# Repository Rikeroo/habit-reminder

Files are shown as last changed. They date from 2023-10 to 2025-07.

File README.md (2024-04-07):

# Habit Reminder
Low energy physical habit reminder, using RGB LEDs, a small task screen and tactile switches to build useful habits and get tasks done

## DevBoard Prototype:
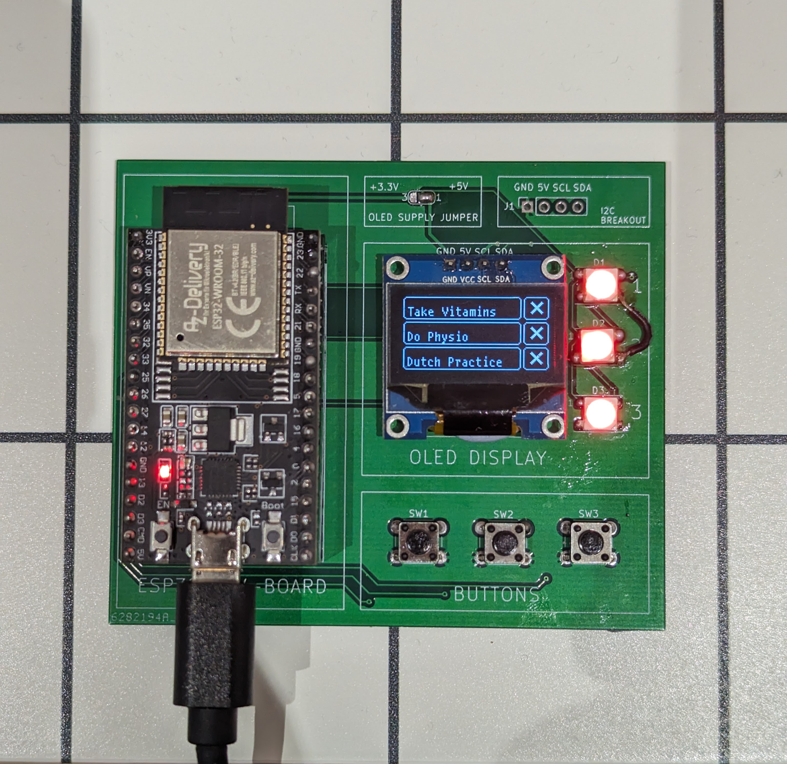
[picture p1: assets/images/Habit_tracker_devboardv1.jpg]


## ESP-32 WROOM Board Render:
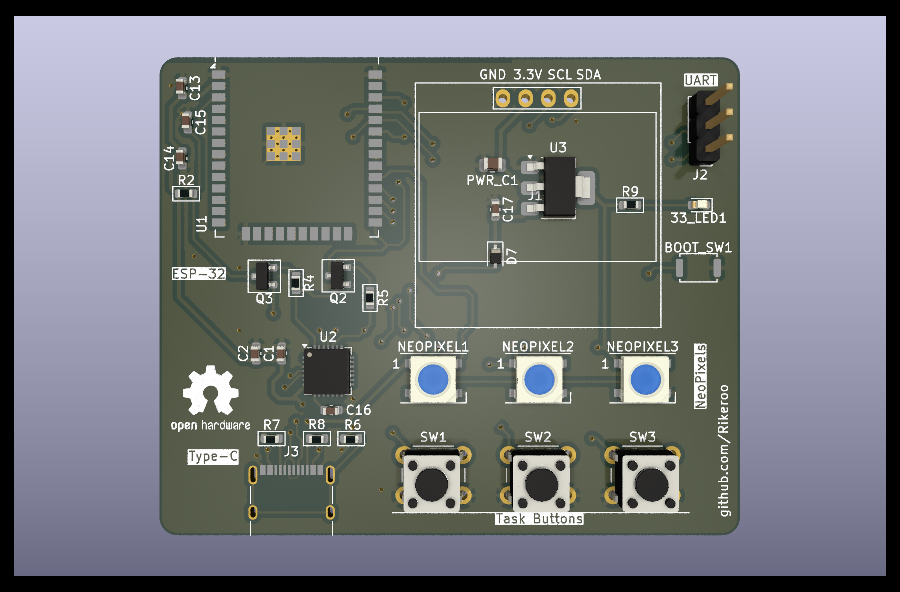
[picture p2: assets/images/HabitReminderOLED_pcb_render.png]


## Features
- OLED screen to display tasks
- NeoPixel WS281b LED modules to show completion at a glance
- Tactile buttons to complete tasks
## Planned Features
- Integration with ToDoist API, with 2-way sync
- FreeRTOS Implementation for easy scheduling
- Speaker for audible task complete sound
- Enclosure/Stand for flexible display options
- Points/Streaks counter
- LED Integrated buttons? (RBG mech switches)

## Learnt from DevBoard V1 Manufacture and build
- WS2812b fine with 5V supply and 3.3V logic
- Status LED would be usefull for de-bugging
- 4 Pin Female socket for screen would make build easier
- Feet required, or Command strip mounting, or enclosure
- Moving NeoPixels away from screen would make for easier soldering
- Add mounting holes to main pcb for enclosure

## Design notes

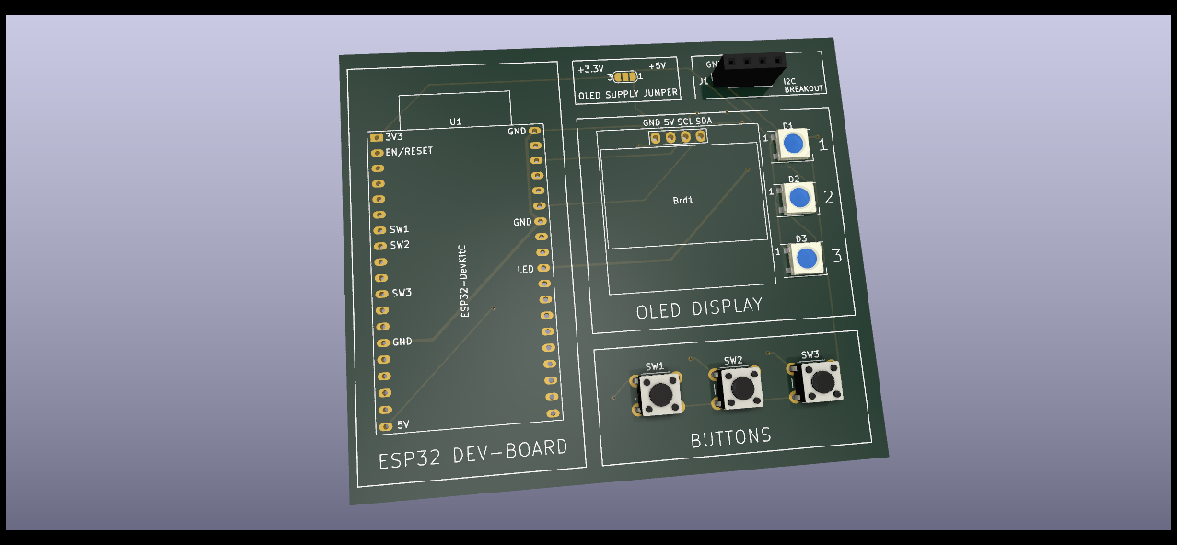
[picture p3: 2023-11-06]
pcb/dev-board-habit-reminder/Dev_habit_reminder/Dev_habit_reminder.png

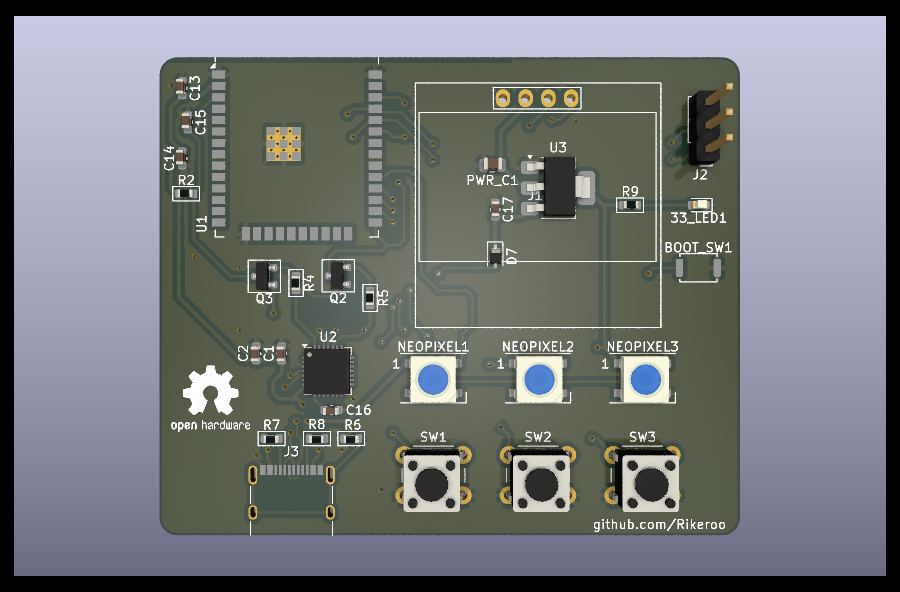
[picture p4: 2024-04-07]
pcb/HabitReminderXAIO/HabitReminderOLED_pcb_render.png

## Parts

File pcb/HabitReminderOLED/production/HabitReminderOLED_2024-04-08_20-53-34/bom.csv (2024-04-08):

Designator | Footprint | Quantity | Value | LCSC Part #
33_LED1 | 0603 | 1 | 3.3 LED
BOOT_SW1 | SW_Push_SPST_NO_Alps_SKRK | 1 | Boot
C1 | 0603 | 1 | 4.7uF
C13, C16, C17 | 0603 | 3 | 10uF
C14, C15, C2 | 0603 | 3 | 0.1uF
D7 | D_SOD-323 | 1 | 1N5819WS
J1 | 128x64OLED_No_Holes | 1 | I2C Sockets
J2 | PinHeader_1x03_P2.54mm_Vertical | 1 | UART Pins
J3 | USB_C_Receptacle_XKB_U262-16XN-4BVC11 | 1 | USB_C_Receptacle_USB2.0_16P
NEOPIXEL1, NEOPIXEL2, NEOPIXEL3 | LED_WS2812B_PLCC4_5.0x5.0mm_P3.2mm | 3 | WS2812B
PWR_C1 | 0805 | 1 | 10uF
Q2, Q3 | SOT-23 | 2 | S8050
R2 | 0603 | 1 | 10k
R4, R5 | 0603 | 2 | 12K
R6 | 0603 | 1 | 1M
R7, R8 | 0603 | 2 | 5.11K
R9 | 0603 | 1 | 2.2K
SW1 | SW_PUSH_6mm | 1 | PUSH_1
SW2 | SW_PUSH_6mm | 1 | PUSH_2
SW3 | SW_PUSH_6mm | 1 | PUSH_3
U1 | ESP32-WROOM-32D | 1 | ESP32-WROOM-32D
U2 | QFN-28-1EP_5x5mm_P0.5mm_EP3.35x3.35mm | 1 | CP2102N-Axx-xQFN28
U3 | SOT-223-3_TabPin2 | 1 | AMS1117-3.3

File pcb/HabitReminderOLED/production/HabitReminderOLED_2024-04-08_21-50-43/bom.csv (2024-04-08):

Designator | Footprint | Quantity | Value | LCSC Part #
33_LED1 | 0603 | 1 | 3.3 LED | C965799
BOOT_SW1 | SW_Push_SPST_NO_Alps_SKRK | 1 | Boot | C455280
C1 | 0603 | 1 | 4.7uF
C13, C16, C17 | 0603 | 3 | 10uF
C14, C15, C2 | 0603 | 3 | 0.1uF
D7 | D_SOD-323 | 1 | 1N5819WS
J1 | 128x64OLED_No_Holes | 1 | I2C Sockets | C2718488
J2 | PinHeader_1x03_P2.54mm_Vertical | 1 | UART Pins | C49257
J3 | USB_C_Receptacle_XKB_U262-16XN-4BVC11 | 1 | USB_C_Receptacle_USB2.0_16P | C319148
NEOPIXEL1, NEOPIXEL2, NEOPIXEL3 | LED_WS2812B_PLCC4_5.0x5.0mm_P3.2mm | 3 | WS2812B | C2843785
PWR_C1 | 0805 | 1 | 10uF
Q2, Q3 | SOT-23 | 2 | S8050 | C916390
R2 | 0603 | 1 | 10k
R4, R5 | 0603 | 2 | 12K
R6 | 0603 | 1 | 1M
R7, R8 | 0603 | 2 | 5.11K
R9 | 0603 | 1 | 2.2K
SW1 | SW_Push_1P1T_NO_6x6mm_H9.5mm | 1 | PUSH_1 | C455110
SW2 | SW_Push_1P1T_NO_6x6mm_H9.5mm | 1 | PUSH_2 | C455110
SW3 | SW_Push_1P1T_NO_6x6mm_H9.5mm | 1 | PUSH_3 | C455110
U1 | ESP32-WROOM-32D | 1 | ESP32-WROOM-32D
U2 | QFN-28-1EP_5x5mm_P0.5mm_EP3.35x3.35mm | 1 | CP2102N-Axx-xQFN28 | C964632
U3 | SOT-223-3_TabPin2 | 1 | AMS1117-3.3 | C347222

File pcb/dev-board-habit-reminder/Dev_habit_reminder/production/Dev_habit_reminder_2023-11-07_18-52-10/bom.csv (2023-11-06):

Designator | Footprint | Quantity | Value | LCSC Part #
Brd1 | 128x64OLED_No_Holes | 1 | SSD1306
D1, D2, D3 | LED_WS2812B_PLCC4_5.0x5.0mm_P3.2mm | 3 | WS2812B
J1 | PinSocket_1x04_P2.54mm_Vertical | 1 | I2C BREAKOUT
JP1 | SolderJumper-3_P1.3mm_Bridged12_RoundedPad1.0x1.5mm_NumberLabels | 1 | SolderJumper_5V_3V3
SW1, SW2, SW3 | SW_PUSH_6mm | 3 | SW_Push
U1 | ESP32-DevKitC_Shield2 | 1 | ESP32-DevKitC

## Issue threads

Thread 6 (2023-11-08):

Add mmWave presence sensor to dev-board

Rikeroo, 2023-11-08:

Rikeroo, 2023-11-08:
Not worth it - oled doesn't consume much power and presence sensor library not trivial to communicate with

Closed 2023-11-08.

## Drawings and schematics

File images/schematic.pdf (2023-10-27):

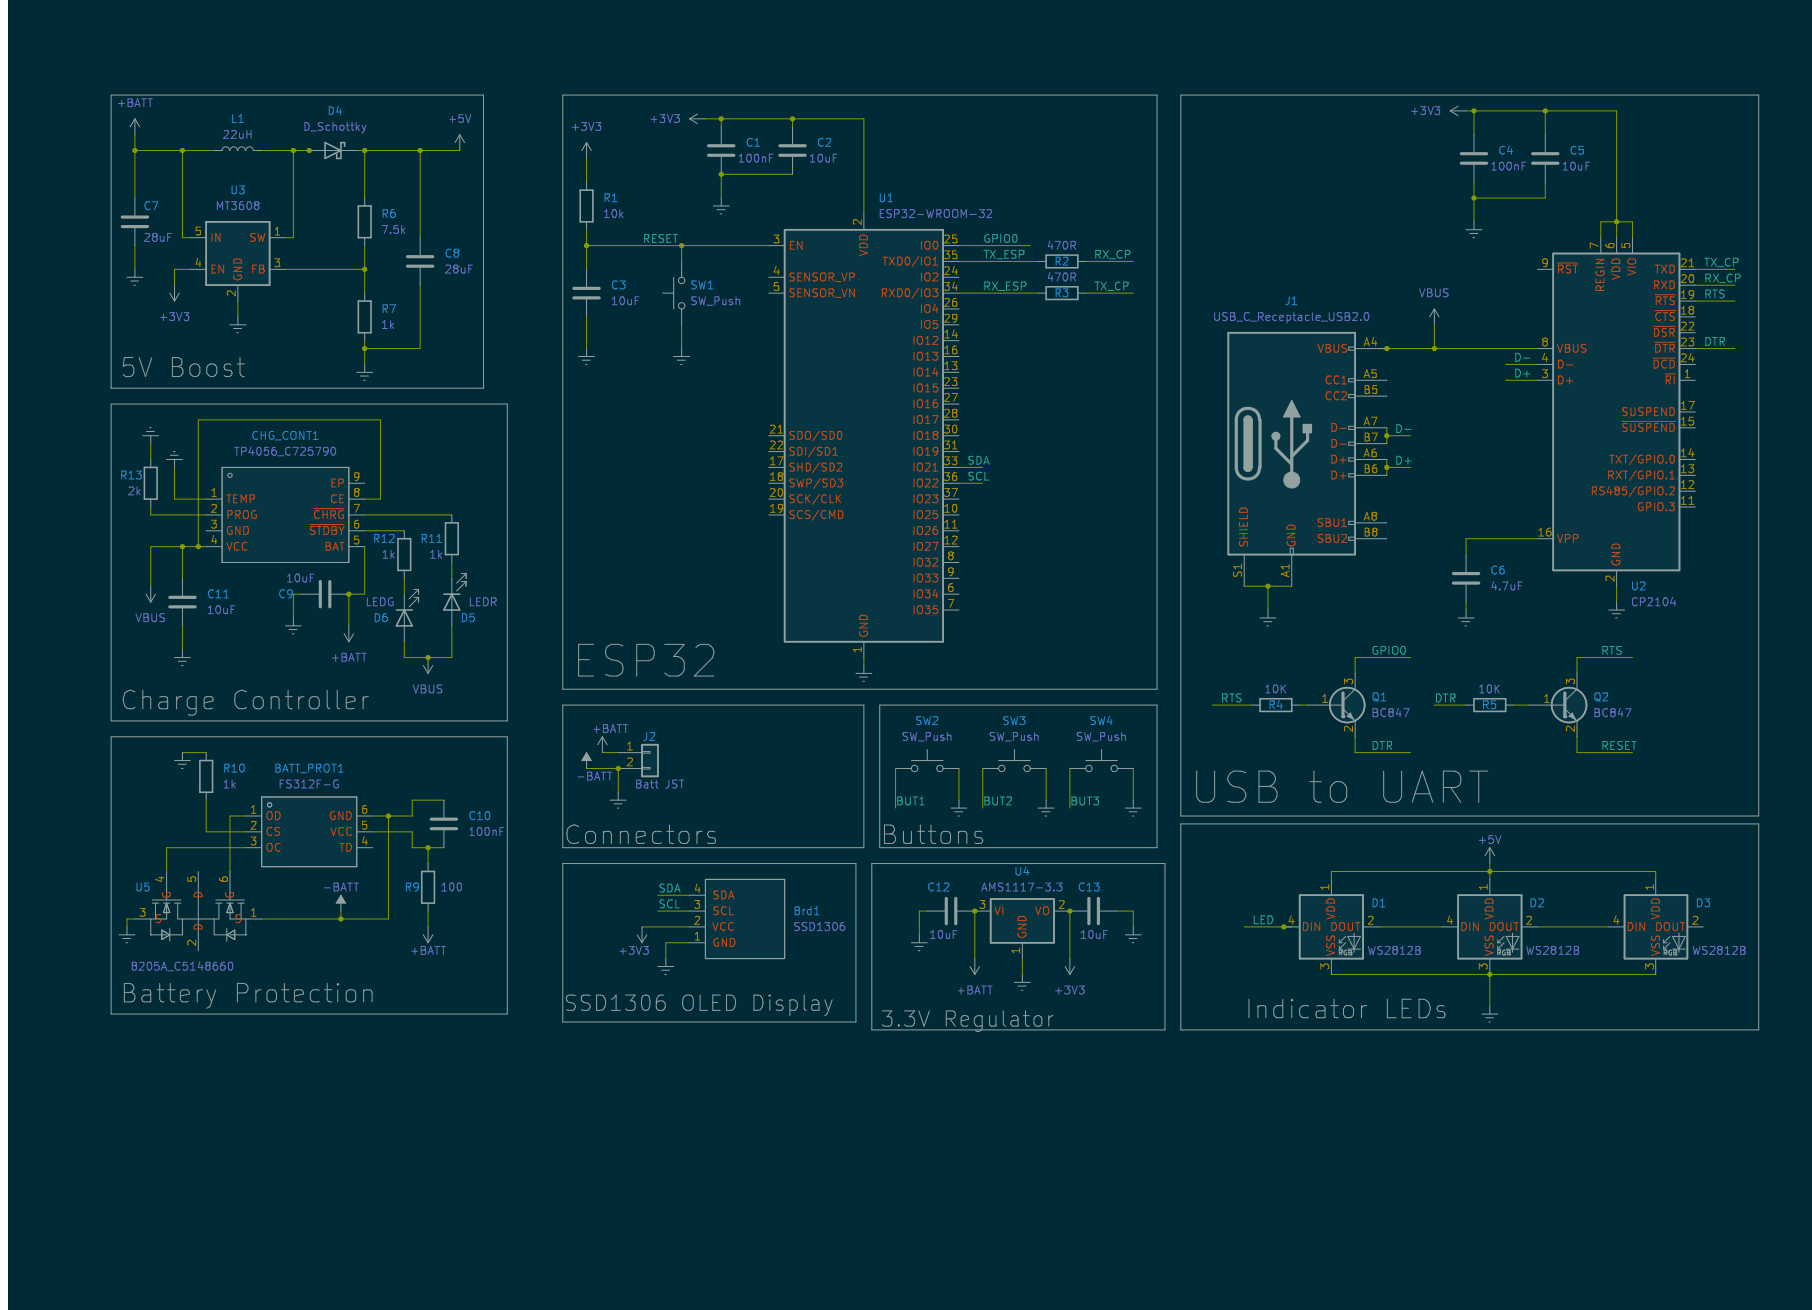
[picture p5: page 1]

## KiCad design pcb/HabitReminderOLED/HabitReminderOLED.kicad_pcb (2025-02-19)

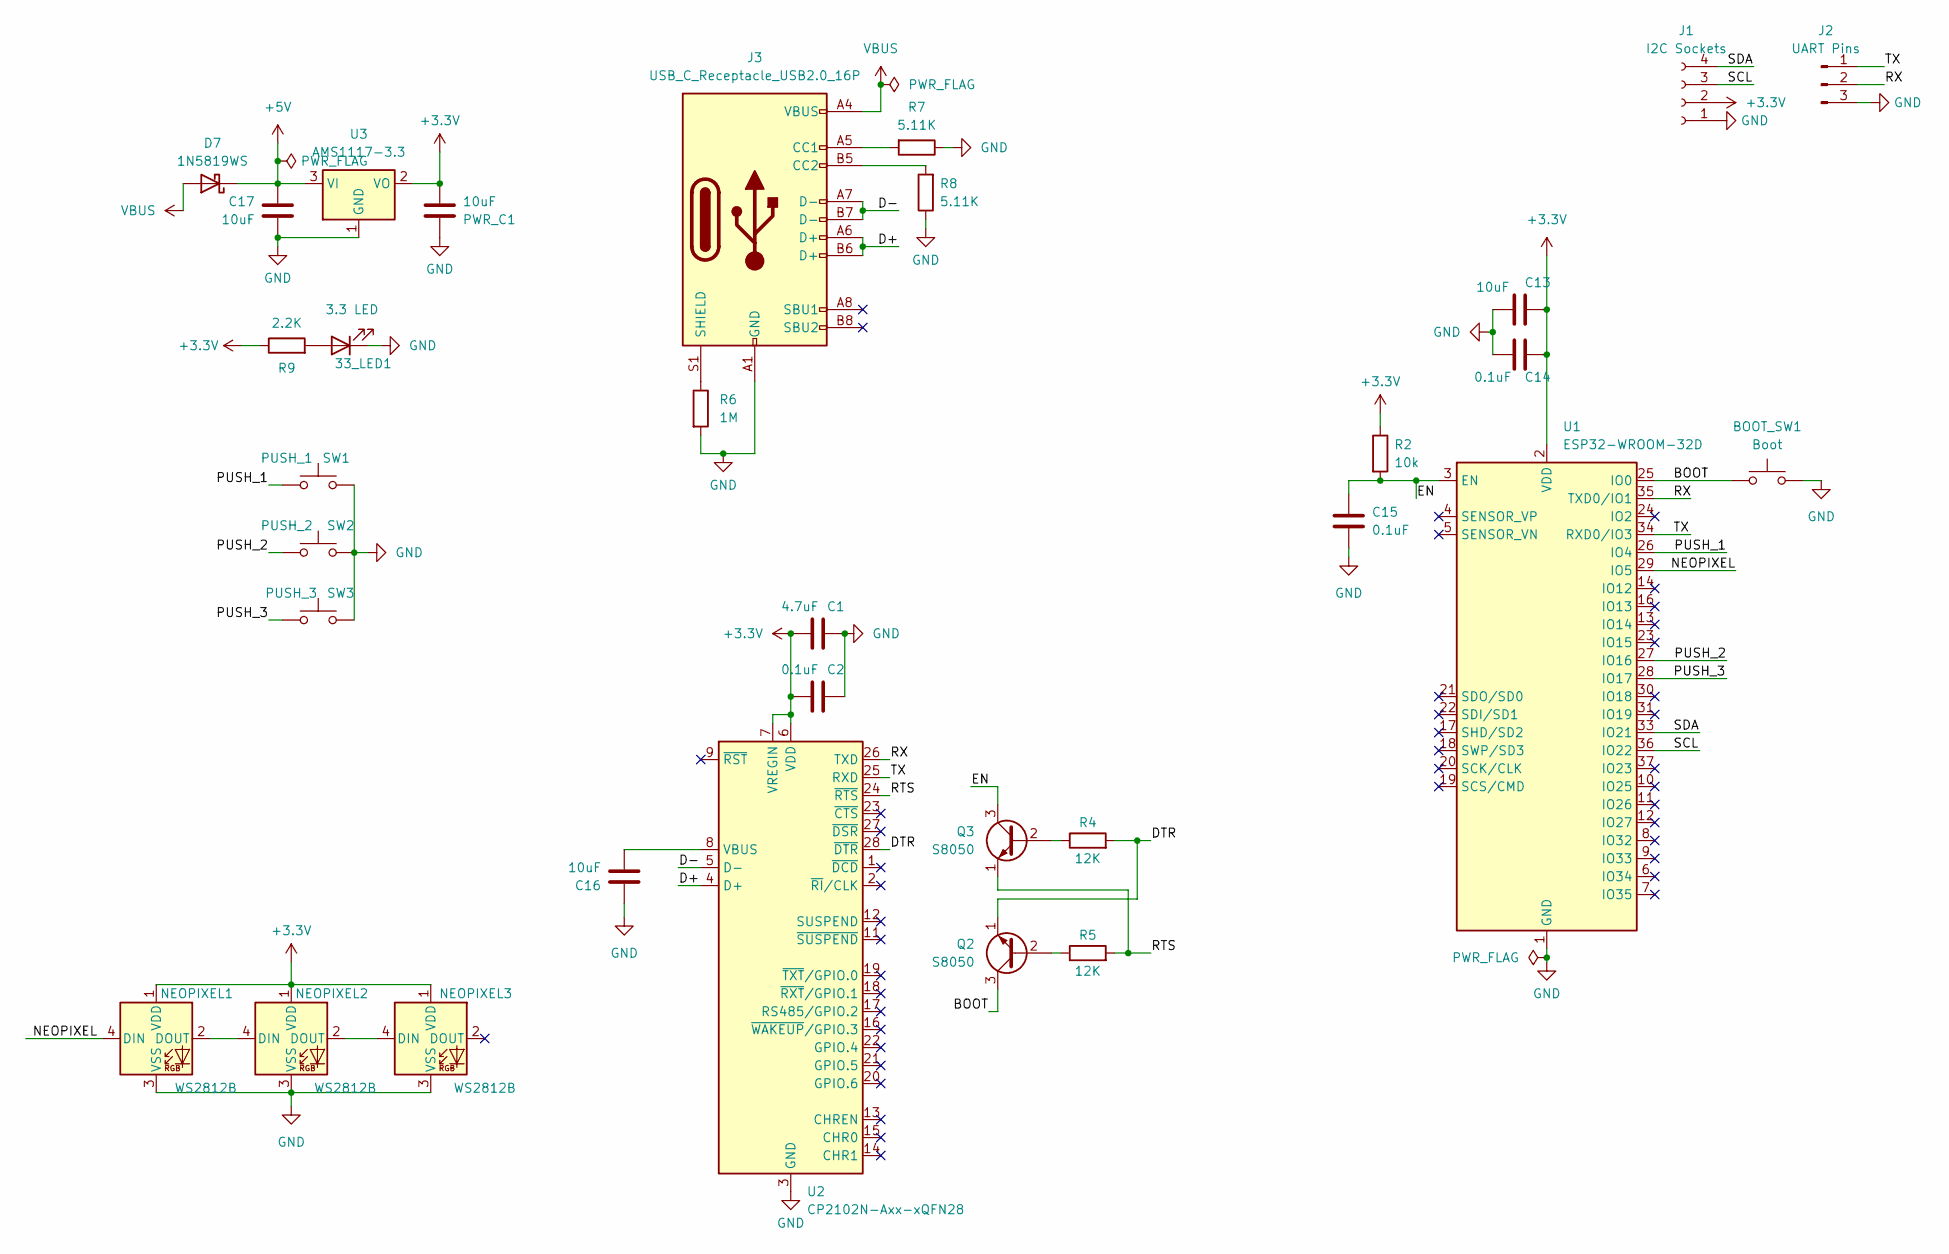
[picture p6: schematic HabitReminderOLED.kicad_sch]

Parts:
33_LED1: 3.3 LED; LED_0603_1608Metric; LCSC C965799
BOOT_SW1: Boot; SW_Push_SPST_NO_Alps_SKRK; LCSC C455280
C1: 4.7uF; C_0603_1608Metric; LCSC C1705
C2, C14, C15: 0.1uF; C_0603_1608Metric; LCSC C30926
C13, C16, C17: 10uF; C_0603_1608Metric; LCSC C77044
D7: 1N5819WS; D_SOD-323; LCSC C2828425
J1: I2C Sockets; 128x64OLED_No_Holes; LCSC C2718488
J2: UART Pins; PinHeader_1x03_P2.54mm_Vertical; LCSC C49257
J3: USB_C_Receptacle_USB2.0_16P; USB_C_Receptacle_XKB_U262-16XN-4BVC11; LCSC C319148
NEOPIXEL1, NEOPIXEL2, NEOPIXEL3: WS2812B; LED_WS2812B_PLCC4_5.0x5.0mm_P3.2mm; LCSC C2843785
PWR_C1: 10uF; C_0805_2012Metric; LCSC C15850
Q2, Q3: S8050; SOT-23; LCSC C916390
R2: 10k; R_0603_1608Metric; LCSC C25804
R4, R5: 12K; R_0603_1608Metric; LCSC C114659
R6: 1M; R_0603_1608Metric; LCSC C26098
R7, R8: 5.11K; R_0603_1608Metric; LCSC C2933233
R9: 2.2K; R_0603_1608Metric; LCSC C4190
SW1: PUSH_1; SW_Push_1P1T_NO_6x6mm_H9.5mm; LCSC C455110
SW2: PUSH_2; SW_Push_1P1T_NO_6x6mm_H9.5mm; LCSC C455110
SW3: PUSH_3; SW_Push_1P1T_NO_6x6mm_H9.5mm; LCSC C455110
U1: ESP32-WROOM-32D; LCSC C473012
U2: CP2102N-Axx-xQFN28; QFN-28-1EP_5x5mm_P0.5mm_EP3.35x3.35mm; LCSC C964632
U3: AMS1117-3.3; SOT-223-3_TabPin2; LCSC C347222

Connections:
+3.3V: C1.1, C2.1, C13.2, C14.2, J1.2, NEOPIXEL1.1 (VDD), NEOPIXEL2.1 (VDD), NEOPIXEL3.1 (VDD), PWR_C1.1, R2.1, R9.1, U1.2 (VDD), U2.6 (VDD), U2.7 (VREGIN), U3.2 (VO)
+5V: C17.2, D7.1 (K), U3.3 (VI)
/BOOT: BOOT_SW1.1, Q2.3 (C), U1.25 (IO0)
/D+: J3.A6 (D+), J3.B6 (D+), U2.4 (D+)
/D-: J3.A7 (D-), J3.B7 (D-), U2.5 (D-)
/DTR: Q2.1 (E), R4.2, U2.28 (~DTR)
/EN: C15.2, Q3.3 (C), R2.2, U1.3 (EN)
/NEOPIXEL: NEOPIXEL1.4 (DIN), U1.29 (IO5)
/PUSH_1: SW1.1, U1.26 (IO4)
/PUSH_2: SW2.1, U1.27 (IO16)
/PUSH_3: SW3.1, U1.28 (IO17)
/RTS: Q3.1 (E), R5.2, U2.24 (~RTS)
/RX: J2.2, U1.35 (TXD0/IO1), U2.26 (TXD)
/SCL: J1.3, U1.36 (IO22)
/SDA: J1.4, U1.33 (IO21)
/TX: J2.1, U1.34 (RXD0/IO3), U2.25 (RXD)
GND: 33_LED1.1 (K), BOOT_SW1.2, C1.2, C2.2, C13.1, C14.1, C15.1, C16.1, C17.1, J1.1, J2.3, J3.A1 (GND), J3.A12 (GND), J3.B1 (GND), J3.B12 (GND), NEOPIXEL1.3 (VSS), NEOPIXEL2.3 (VSS), NEOPIXEL3.3 (VSS), PWR_C1.2, R6.2, R7.1, R8.1, SW1.2, SW2.2, SW3.2, U1.1 (GND), U1.15 (GND), U1.38 (GND), U1.39 (GND), U2.3 (GND), U2.29 (GND), U3.1 (GND)
unnamed: 33_LED1.2 (A), R9.2
unnamed: J3.A5 (CC1), R7.2
unnamed: J3.B5 (CC2), R8.2
unnamed: J3.S1 (SHIELD), R6.1
unnamed: NEOPIXEL1.2 (DOUT), NEOPIXEL2.4 (DIN)
unnamed: NEOPIXEL2.2 (DOUT), NEOPIXEL3.4 (DIN)
unnamed: Q2.2 (B), R5.1
unnamed: Q3.2 (B), R4.1
unnamed: C16.2, U2.8 (VBUS)
VBUS: D7.2 (A), J3.A4 (VBUS), J3.A9 (VBUS), J3.B4 (VBUS), J3.B9 (VBUS)

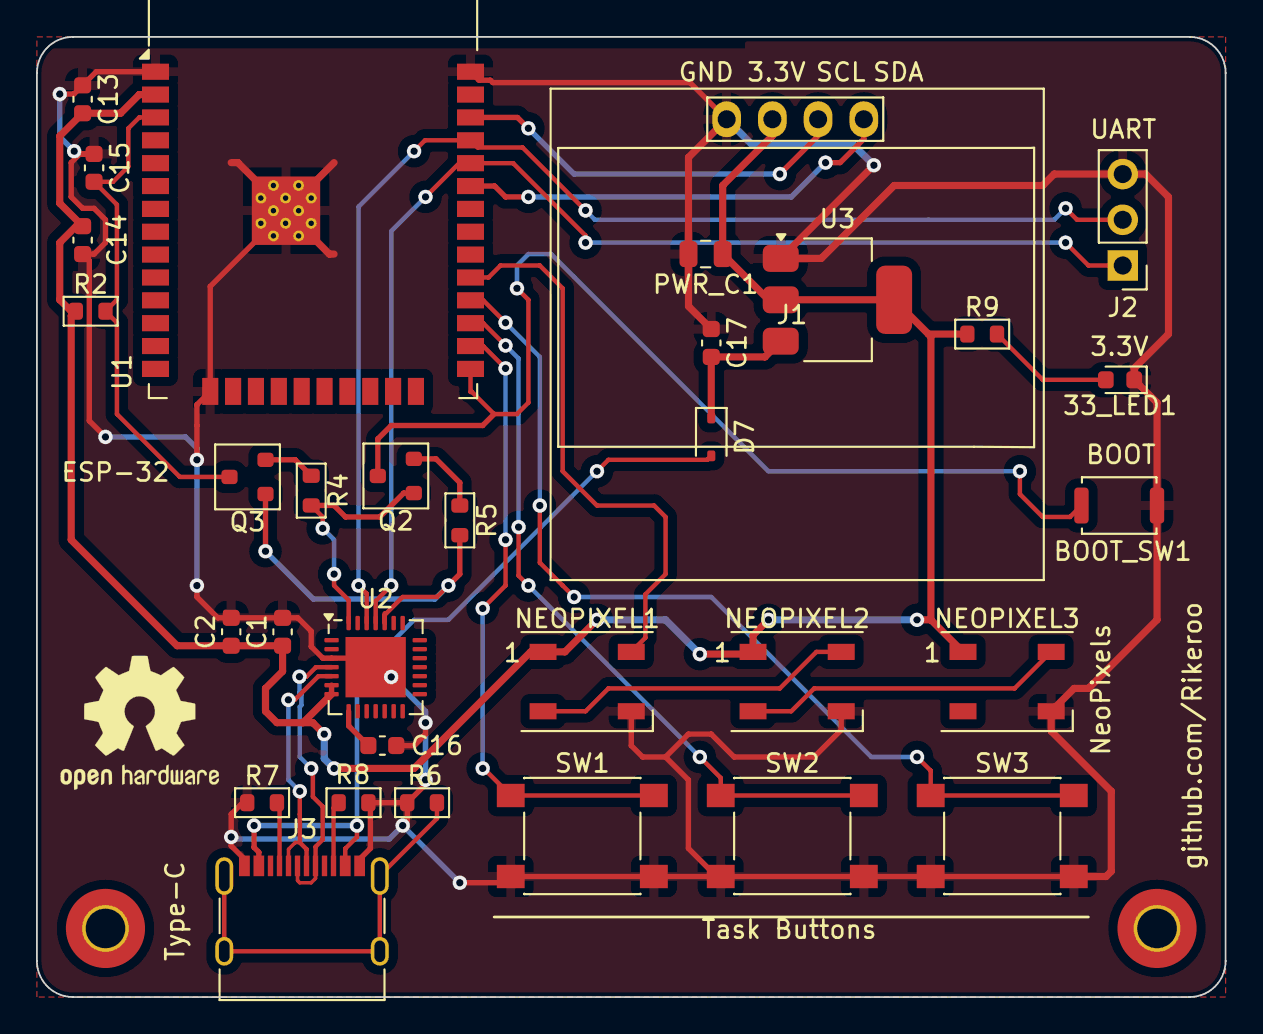
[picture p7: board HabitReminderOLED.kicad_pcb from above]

Board: 2 copper layers, 66.0 x 53.3 mm, 32 parts (0 on the bottom side), 27 nets.

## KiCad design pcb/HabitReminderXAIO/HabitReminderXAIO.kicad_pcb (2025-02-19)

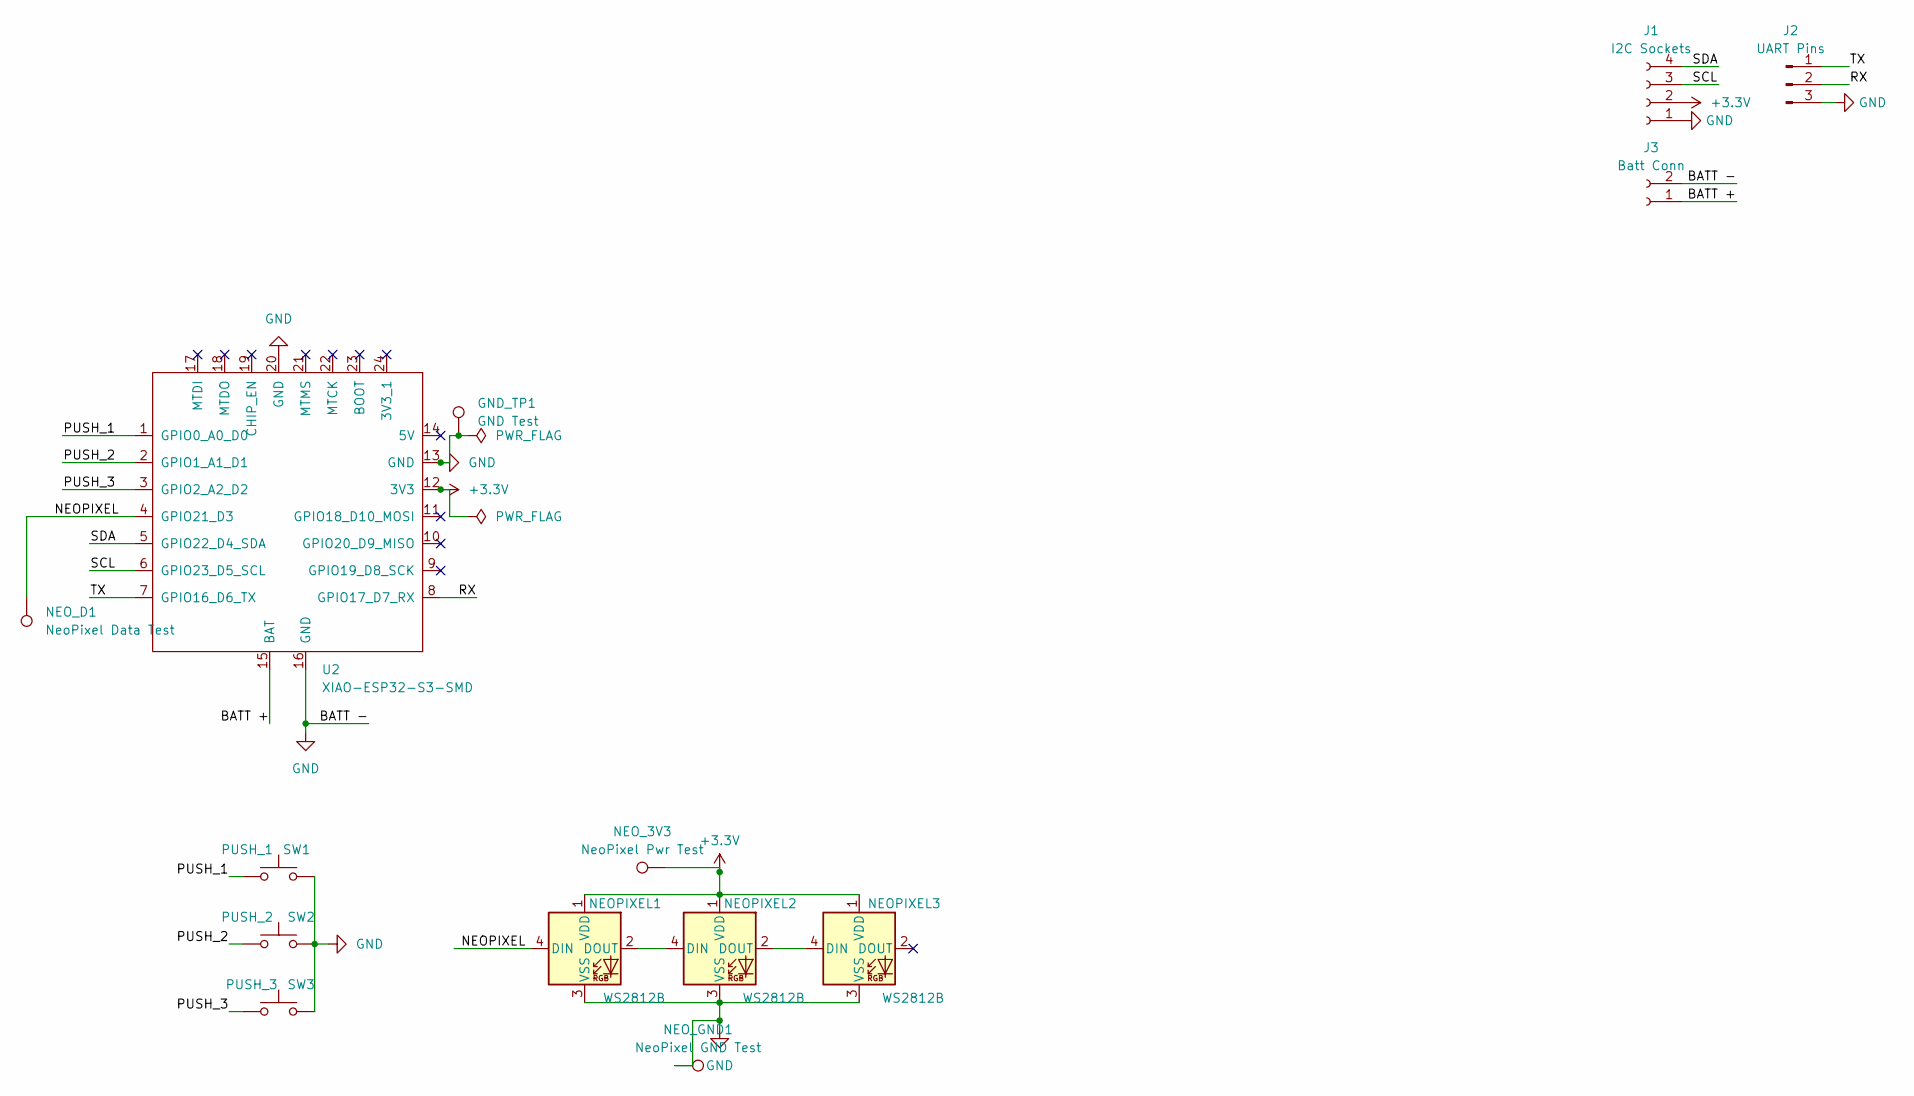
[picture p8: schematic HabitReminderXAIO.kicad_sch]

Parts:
GND_TP1: GND Test; TestPoint_Pad_D1.5mm
J1: I2C Sockets; 128x64OLED; LCSC C2718488
J2: UART Pins; PinHeader_1x03_P2.54mm_Vertical; LCSC C49257
J3: Batt Conn; JST_PH_S2B-PH-K_1x02_P2.00mm_Horizontal
NEOPIXEL1, NEOPIXEL2, NEOPIXEL3: WS2812B; LED_WS2812B_PLCC4_5.0x5.0mm_P3.2mm; LCSC C2843785
NEO_3V3: NeoPixel Pwr Test; TestPoint_Pad_D1.5mm
NEO_D1: NeoPixel Data Test; TestPoint_Pad_D1.5mm
NEO_GND1: NeoPixel GND Test; TestPoint_Pad_D1.5mm
SW1: PUSH_1; SW_Push_1P1T_NO_6x6mm_H9.5mm; LCSC C455110
SW2: PUSH_2; SW_Push_1P1T_NO_6x6mm_H9.5mm; LCSC C455110
SW3: PUSH_3; SW_Push_1P1T_NO_6x6mm_H9.5mm; LCSC C455110
U2: XIAO-ESP32-S3-SMD; XIAO-ESP32C6-SMD

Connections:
+3.3V: J1.2, NEOPIXEL1.1 (VDD), NEOPIXEL2.1 (VDD), NEOPIXEL3.1 (VDD), NEO_3V3.1, U2.12 (3V3)
/BATT +: J3.1, U2.15 (BAT)
/NEOPIXEL: NEOPIXEL1.4 (DIN), NEO_D1.1, U2.4 (GPIO21_D3)
/PUSH_1: SW1.1, U2.1 (GPIO0_A0_D0)
/PUSH_2: SW2.1, U2.2 (GPIO1_A1_D1)
/PUSH_3: SW3.1, U2.3 (GPIO2_A2_D2)
/RX: J2.2, U2.8 (GPIO17_D7_RX)
/SCL: J1.3, U2.6 (GPIO23_D5_SCL)
/SDA: J1.4, U2.5 (GPIO22_D4_SDA)
/TX: J2.1, U2.7 (GPIO16_D6_TX)
GND: GND_TP1.1, J1.1, J2.3, J3.2, NEOPIXEL1.3 (VSS), NEOPIXEL2.3 (VSS), NEOPIXEL3.3 (VSS), NEO_GND1.1, SW1.2, SW2.2, SW3.2, U2.13 (GND), U2.16 (GND), U2.20 (GND)
unnamed: NEOPIXEL1.2 (DOUT), NEOPIXEL2.4 (DIN)
unnamed: NEOPIXEL2.2 (DOUT), NEOPIXEL3.4 (DIN)

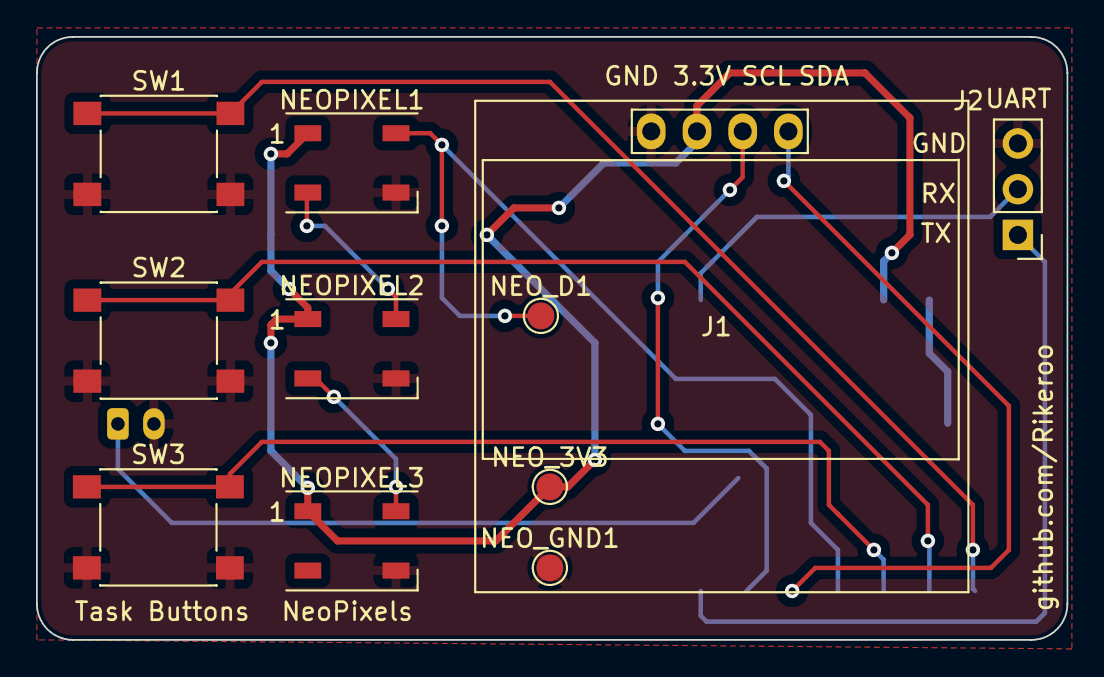
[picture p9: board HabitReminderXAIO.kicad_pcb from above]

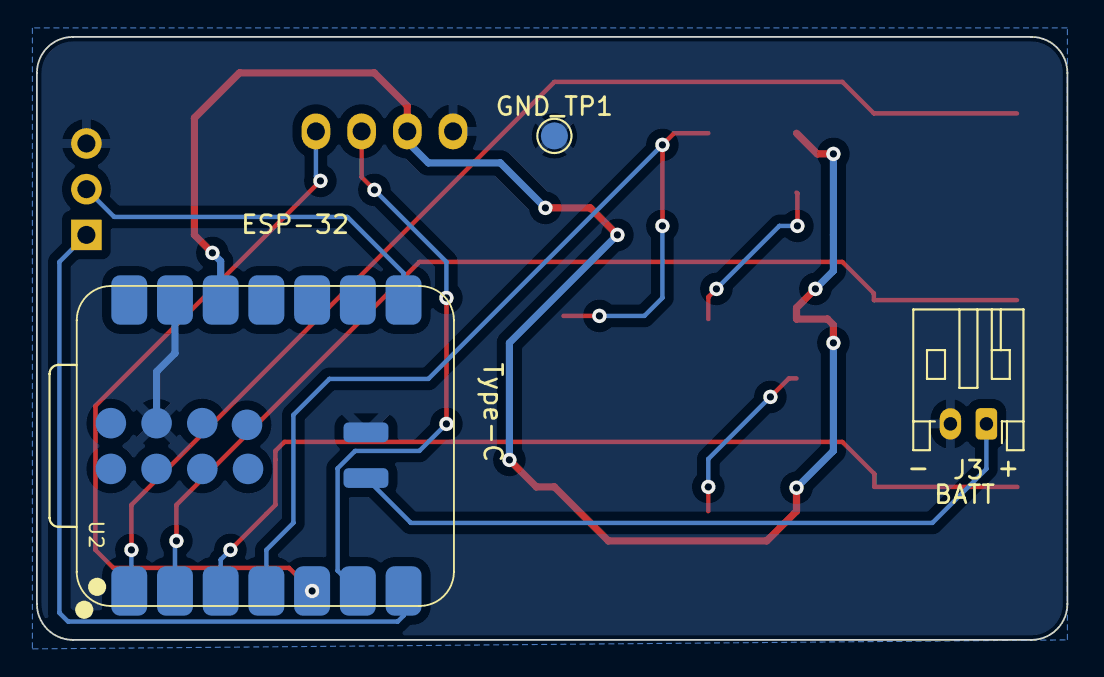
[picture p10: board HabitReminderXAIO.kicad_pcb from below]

Board: 2 copper layers, 57.2 x 33.5 mm, 14 parts (3 on the bottom side), 13 nets.

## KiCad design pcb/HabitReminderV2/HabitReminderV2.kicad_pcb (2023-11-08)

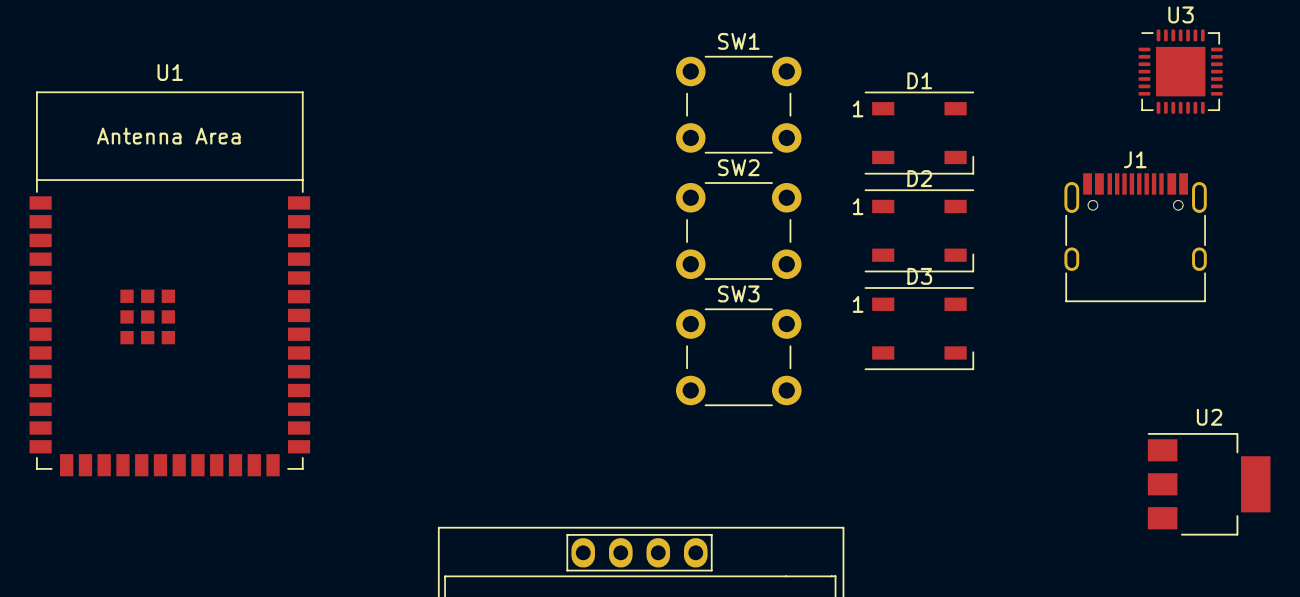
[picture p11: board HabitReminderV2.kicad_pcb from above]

Board: 2 copper layers, 11 parts (0 on the bottom side), 13 nets, no tracks yet.

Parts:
Brd1: SSD1306; 128x64OLED_No_Holes
D1, D2, D3: WS2812B; LED_WS2812B_PLCC4_5.0x5.0mm_P3.2mm
J1: USB_C_Receptacle_USB2.0; USB_C_Receptacle_HRO_TYPE-C-31-M-12
SW1, SW2, SW3: SW_Push; SW_PUSH_6mm
U1: ESP32-S3-WROOM-1
U2: LD1117S33TR_SOT223; SOT-223-3_TabPin2
U3: CP2102N-Axx-xQFN28; QFN-28-1EP_5x5mm_P0.5mm_EP3.35x3.35mm

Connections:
+5V: Brd1.2 (VCC), D1.1 (VDD), D2.1 (VDD), D3.1 (VDD)
/D+: J1.A6 (D+), J1.B6 (D+), U3.4 (D+)
/D-: J1.A7 (D-), J1.B7 (D-), U3.5 (D-)
/LED: D1.4 (DIN), U1.6 (GPIO6/TOUCH6/ADC1_CH5)
/SCL: Brd1.3 (SCL), U1.11 (GPIO18/U1RXD/ADC2_CH7/CLK_OUT3)
/SDA: Brd1.4 (SDA), U1.10 (GPIO17/U1TXD/ADC2_CH6)
/SW1: SW1.2, U1.21 (GPIO13/TOUCH13/ADC2_CH2/FSPIQ/FSPIIO7/S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)
/SW2: SW2.2, U1.20 (GPIO12/TOUCH12/ADC2_CH1/FSPICLK/FSPIIO6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)
/SW3: SW3.2, U1.19 (GPIO11/TOUCH11/ADC2_CH0/FSPID/FSPIIO5/S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)
GND: Brd1.1 (GND), D1.3 (VSS), D2.3 (VSS), D3.3 (VSS), J1.A1 (GND), J1.A12 (GND), J1.B1 (GND), J1.B12 (GND), J1.S1 (SHIELD), SW1.1, SW2.1, SW3.1, U1.1 (GND), U1.40 (GND), U1.41 (GND), U2.1 (GND), U3.3 (GND), U3.29 (GND)
unnamed: D1.2 (DOUT), D2.4 (DIN)
unnamed: D2.2 (DOUT), D3.4 (DIN)
unnamed: J1.A4 (VBUS), J1.A9 (VBUS), J1.B4 (VBUS), J1.B9 (VBUS)

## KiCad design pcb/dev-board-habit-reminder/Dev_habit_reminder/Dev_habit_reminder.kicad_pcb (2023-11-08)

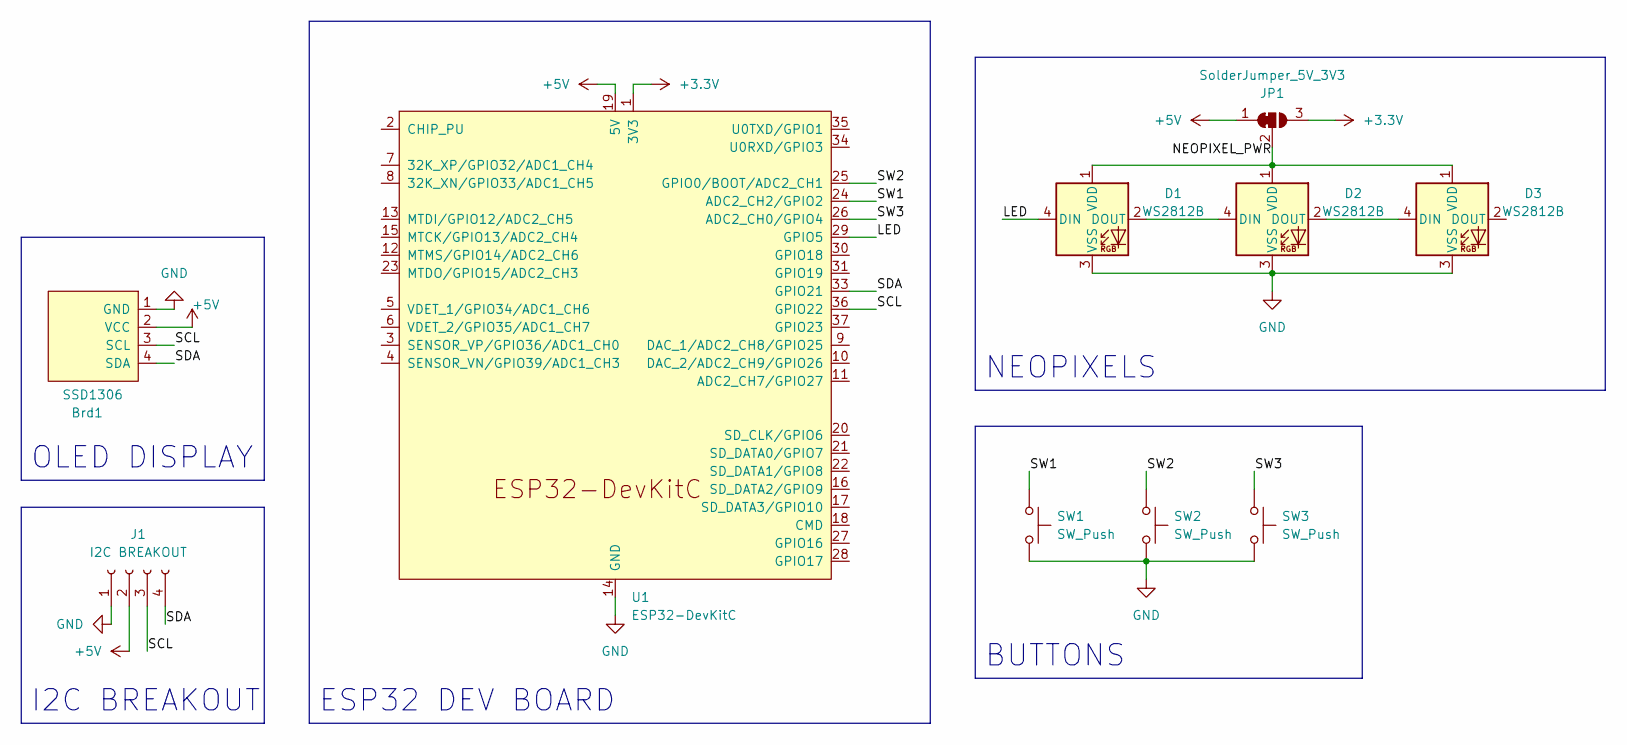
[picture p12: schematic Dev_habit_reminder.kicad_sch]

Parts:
Brd1: SSD1306; 128x64OLED_No_Holes
D1, D3: WS2812B; LED_WS2812B_PLCC4_5.0x5.0mm_P3.2mm; MPN C2843785
D2: WS2812B; LED_WS2812B_PLCC4_5.0x5.0mm_P3.2mm
J1: I2C BREAKOUT; PinSocket_1x04_P2.54mm_Vertical
JP1: SolderJumper_5V_3V3; SolderJumper-3_P1.3mm_Bridged12_RoundedPad1.0x1.5mm_NumberL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
SW1, SW2, SW3: SW_Push; SW_PUSH_6mm; MPN C410366
U1: ESP32-DevKitC; ESP32-DevKitC_Shield2

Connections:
+3.3V: JP1.3 (B), U1.1 (3V3)
+5V: Brd1.2 (VCC), J1.2, JP1.1 (A), U1.19 (5V)
/LED: D1.4 (DIN), U1.29 (GPIO5)
/NEOPIXEL_PWR: D1.1 (VDD), D2.1 (VDD), D3.1 (VDD), JP1.2 (C)
/SCL: Brd1.3 (SCL), J1.3, U1.36 (GPIO22)
/SDA: Brd1.4 (SDA), J1.4, U1.33 (GPIO21)
/SW1: SW1.1, U1.24 (ADC2_CH2/GPIO2)
/SW2: SW2.1, U1.25 (GPIO0/BOOT/ADC2_CH1)
/SW3: SW3.1, U1.26 (ADC2_CH0/GPIO4)
GND: Brd1.1 (GND), D1.3 (VSS), D2.3 (VSS), D3.3 (VSS), J1.1, SW1.2, SW2.2, SW3.2, U1.14 (GND), U1.32 (GND), U1.38 (GND)
unnamed: D1.2 (DOUT), D2.4 (DIN)
unnamed: D2.2 (DOUT), D3.4 (DIN)

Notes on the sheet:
I2C BREAKOUT
BUTTONS
ESP32 DEV BOARD
OLED DISPLAY
NEOPIXELS

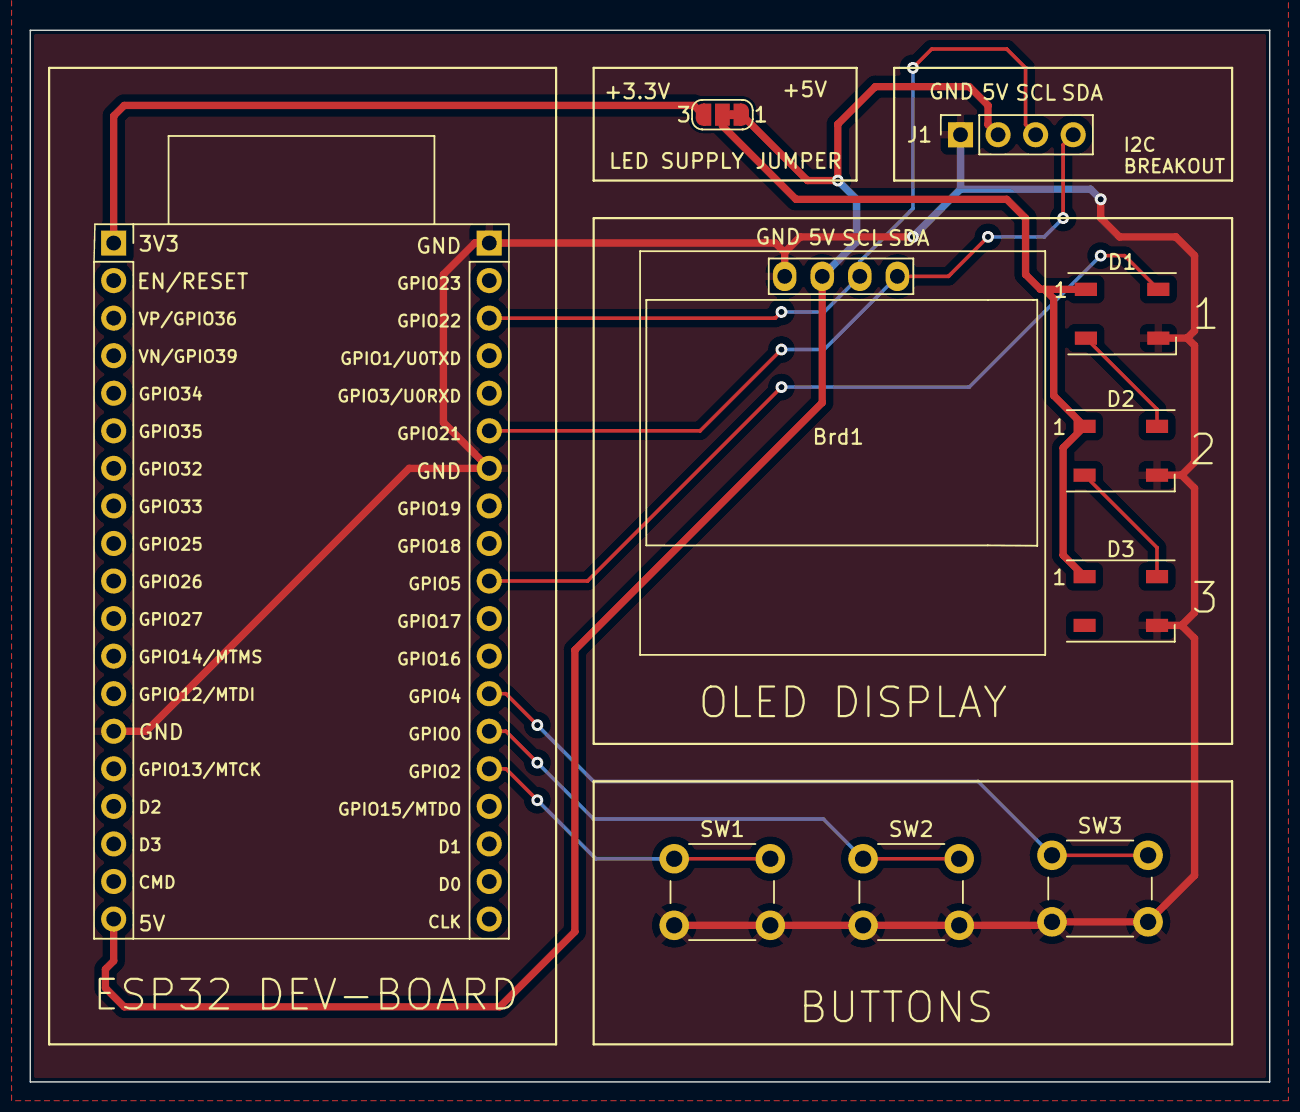
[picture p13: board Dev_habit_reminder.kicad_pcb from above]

Board: 2 copper layers, 83.8 x 71.1 mm, 10 parts (0 on the bottom side), 12 nets.

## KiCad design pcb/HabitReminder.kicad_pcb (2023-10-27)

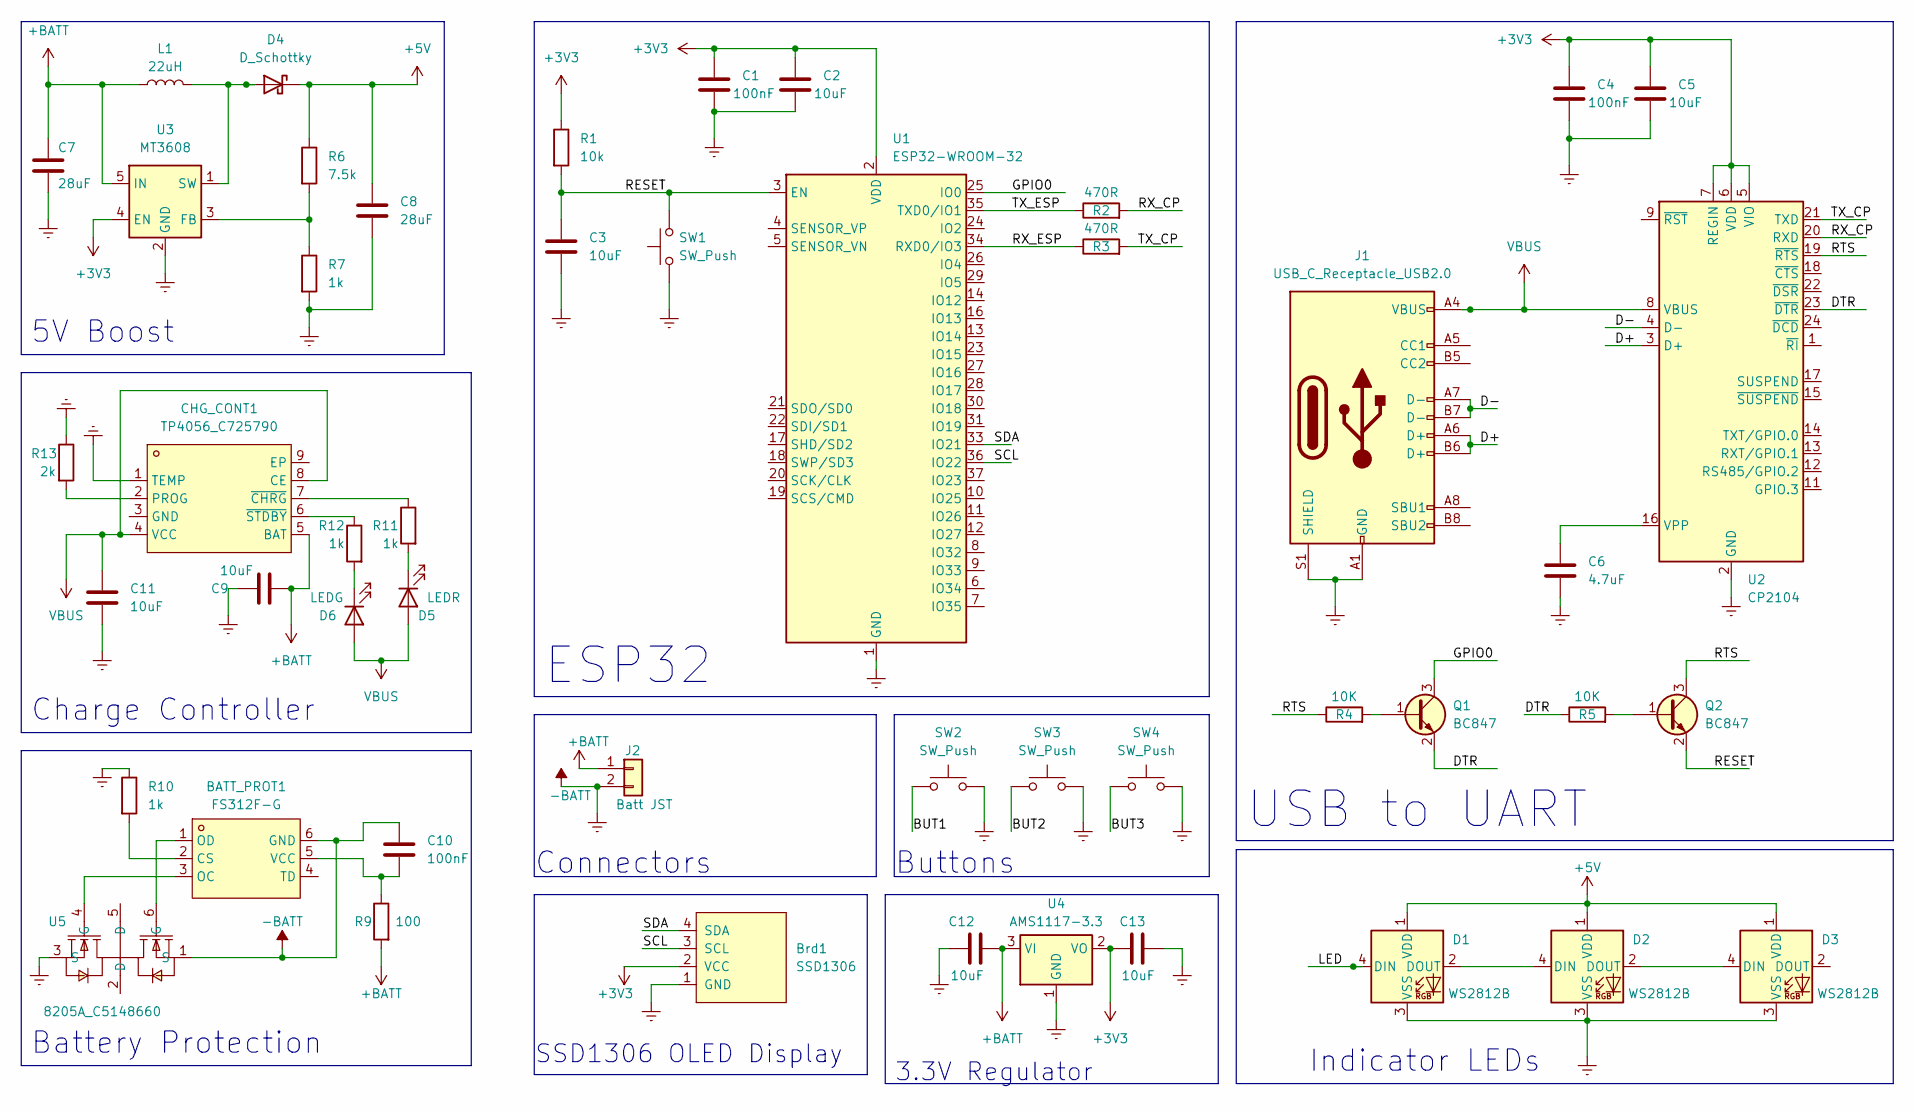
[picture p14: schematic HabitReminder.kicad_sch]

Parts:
BATT_PROT1: FS312F-G; SOT-23-6_L2.9-W1.6-P0.95-LS2.8-BR; LCSC Part C82736
Brd1: SSD1306; 128x64OLED
C1, C4, C10: 100nF; C_0805_2012Metric
C2, C3, C5, C9, C11, C12, C13: 10uF; C_0805_2012Metric
C6: 4.7uF; C_0805_2012Metric
C7, C8: 28uF; C_0805_2012Metric
CHG_CONT1: TP4056_C725790; ESOP-8_L4.9-W3.9-P1.27-LS6.0-BL-EP; LCSC Part C725790
D1, D2, D3: WS2812B; LED_WS2812B_PLCC4_5.0x5.0mm_P3.2mm
D4: D_Schottky; D_SOD-523
D5: LEDR; LED_0805_2012Metric
D6: LEDG; LED_0805_2012Metric
J1: USB_C_Receptacle_USB2.0; USB_C_Receptacle_GCT_USB4105-xx-A_16P_TopMnt_Horizontal
J2: Batt JST; R_0805_2012Metric
L1: 22uH; R_0805_2012Metric
Q1, Q2: BC847; SOT-23
R1: 10k; R_0805_2012Metric
R2, R3: 470R; R_0805_2012Metric
R4, R5: 10K; R_0805_2012Metric
R6: 7.5k; R_0805_2012Metric
R7, R10, R11, R12: 1k; R_0805_2012Metric
R9: 100; R_0805_2012Metric
R13: 2k; R_0805_2012Metric
SW1: SW_Push; SW_SPST_TL3305B
SW2, SW3, SW4: SW_Push; SW_PUSH-12mm
U1: ESP32-WROOM-32
U2: CP2104; QFN-24-1EP_4x4mm_P0.5mm_EP2.6x2.6mm
U3: MT3608; SOT-23-6
U4: AMS1117-3.3; SOT-223-3_TabPin2
U5: 8205A_C5148660; SOT-23-6_L2.9-W1.6-P0.95-LS2.8-BR; LCSC Part C5148660

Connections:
+3V3: Brd1.2 (VCC), C1.1, C2.1, C4.1, C5.1, C13.1, R1.1, U1.2 (VDD), U2.5 (VIO), U2.6 (VDD), U2.7 (REGIN), U3.4 (EN), U4.2 (VO)
+5V: C8.1, D1.1 (VDD), D2.1 (VDD), D3.1 (VDD), D4.1 (K), R6.1
+BATT: C7.1, C9.1, C12.2, CHG_CONT1.5 (BAT), J2.1, L1.1, R9.2, U3.5 (IN), U4.3 (VI)
-BATT: BATT_PROT1.6 (GND), Brd1.1 (GND), C1.2, C2.2, C3.2, C4.2, C5.2, C6.2, C7.2, C8.2, C9.2, C10.1, C11.2, C12.1, C13.2, CHG_CONT1.1 (TEMP), D1.3 (VSS), D2.3 (VSS), D3.3 (VSS), J1.A1 (GND), J1.A12 (GND), J1.B1 (GND), J1.B12 (GND), J1.S1 (SHIELD), J2.2, R7.2, R10.1, R13.1, SW1.1, SW2.2, SW3.2, SW4.2, U1.1 (GND), U1.15 (GND), U1.38 (GND), U1.39 (GND), U2.2 (GND), U2.25 (GND), U3.2 (GND), U4.1 (GND), U5.1 (S), U5.3 (S)
/BUT1: SW2.1
/BUT2: SW3.1
/BUT3: SW4.1
/D+: J1.A6 (D+), J1.B6 (D+), U2.3 (D+)
/D-: J1.A7 (D-), J1.B7 (D-), U2.4 (D-)
/DTR: Q1.2 (E), R5.1, U2.23 (~DTR)
/GPIO0: Q1.3 (C), U1.25 (IO0)
/LED: D1.4 (DIN)
/RESET: C3.1, Q2.2 (E), R1.2, SW1.2, U1.3 (EN)
/RTS: Q2.3 (C), R4.1, U2.19 (~RTS)
/RX_CP: R2.2, U2.20 (RXD)
/RX_ESP: R3.1, U1.34 (RXD0/IO3)
/SCL: Brd1.3 (SCL), U1.36 (IO22)
/SDA: Brd1.4 (SDA), U1.33 (IO21)
/TX_CP: R3.2, U2.21 (TXD)
/TX_ESP: R2.1, U1.35 (TXD0/IO1)
unnamed: BATT_PROT1.2 (CS), R10.2
unnamed: BATT_PROT1.3 (OC), U5.4 (G)
unnamed: BATT_PROT1.1 (OD), U5.6 (G)
unnamed: BATT_PROT1.5 (VCC), C10.2, R9.1
unnamed: CHG_CONT1.2 (PROG), R13.2
unnamed: CHG_CONT1.7 (~CHRG), R11.1
unnamed: CHG_CONT1.6 (~STDBY), R12.1
unnamed: D1.2 (DOUT), D2.4 (DIN)
unnamed: D2.2 (DOUT), D3.4 (DIN)
unnamed: D4.2 (A), L1.2, U3.1 (SW)
unnamed: D5.1 (K), R11.2
unnamed: D6.1 (K), R12.2
unnamed: Q1.1 (B), R4.2
unnamed: Q2.1 (B), R5.2
unnamed: C6.1, U2.16 (VPP)
unnamed: R6.2, R7.1, U3.3 (FB)
VBUS: C11.1, CHG_CONT1.4 (VCC), CHG_CONT1.8 (CE), D5.2 (A), D6.2 (A), J1.A4 (VBUS), J1.A9 (VBUS), J1.B4 (VBUS), J1.B9 (VBUS), U2.8 (VBUS)

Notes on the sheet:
Buttons
Charge Controller
USB to UART
Indicator LEDs
ESP32
3.3V Regulator
5V Boost
Battery Protection
SSD1306 OLED Display
Connectors

Board: 2 copper layers, 48 parts (0 on the bottom side), 33 nets, no tracks yet.

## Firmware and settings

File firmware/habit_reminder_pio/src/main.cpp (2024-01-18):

#include <ESPAsyncWebServer.h>
#include <AsyncTCP.h>
#include <Arduino.h>
#include <EasyButton.h>
#include <U8g2lib.h>
#include <Wire.h>
#include <Adafruit_NeoPixel.h>
#include <WiFi.h>
#include <NTPClient.h>
#include <WiFiUdp.h>

// Initialise Display object
U8G2_SSD1306_128X64_NONAME_1_HW_I2C u8g2(U8G2_R0, /* reset=*/ U8X8_PIN_NONE);

// WiFi Details
const char* ssid = "SSID";
const char* password = "PASSWORD";

// Setup NTP
WiFiUDP ntpUDP;
NTPClient timeClient(ntpUDP);

// Set web server port number to 80
WiFiServer server(80);

// Variable to store the HTTP request String heaeder;
String header;

// HTML web page to handle 3 input fields (input1, input2, input3)
const char index_html[] PROGMEM = R"rawliteral(
<!DOCTYPE HTML><html><head>
  <title>ESP Input Form</title>
  <meta name="viewport" content="width=device-width, initial-scale=1">
  </head><body>
  <form action="/get">
    input1: <input type="text" name="input1">
    <input type="submit" value="Submit">
  </form><br>
  <form action="/get">
    input2: <input type="text" name="input2">
    <input type="submit" value="Submit">
  </form><br>
  <form action="/get">
    input3: <input type="text" name="input3">
    <input type="submit" value="Submit">
  </form>
</body></html>)rawliteral";

void notFound(AsyncWebServerRequest *request) {
  request->send(404, "text/plain", "Not found");
}

// NeoPixel Constants
int neoPin = 5;
int numPixels = 3;

// Initialise Neopixels object
Adafruit_NeoPixel pixels(numPixels, neoPin, NEO_GRB + NEO_KHZ800);

// Define menu box parameters
int boxLength = 103; // Menu box length
int boxWidth = 20; // Menu box width
int symbolX = 109; // Symbol X draw coord
int symbolY = 16; // Initial symbol Y

// Define button pins
int button1Pin = 32; // Left-most button pin
int button2Pin = 33; // Middle button
int button3Pin = 27; // Right-most button

int duration = 2000; // Long Press Duration

// Define Task class
class Task {
  public:
    // Attributes
    std::string text;
    bool complete;
    
    // Constructor
    Task(std::string x, bool y) {
      text = x;
      complete = y;
    }
    // Toggles task completeness
    void toggle(){
      complete = !complete;
    }
    bool getComplete(){
      return complete;
    }
    std::string getText(){
      return text;
    }
    void resetTask(){
      complete = false;
    }
};

// Define Task objects
Task task1("Take Vitamins", true);
Task task2("Do Physio", true);
Task task3("Dutch Practice", true);

// Put objects into array
Task tasks[3] = {task1,task2,task3};

// Define buttons
EasyButton button1(button1Pin);
EasyButton button2(button2Pin);
EasyButton button3(button3Pin);

// Put buttons into Array
EasyButton buttons[3] = {button1,button2,button3};

// Define function for each button (required)
void onPress1() {tasks[0].toggle();Serial.println("b1");}
void onPress2() {tasks[1].toggle();Serial.println("b2");}
void onPress3() {tasks[2].toggle();Serial.println("b3");}

void setup() {
  // put your setup code here, to run once:
  Serial.begin(9600);
  u8g2.begin();
  pixels.begin();
  WiFi.begin(ssid, password);
  
  // Initialise Buttons
  button1.begin();
  button2.begin();
  button3.begin();

  // Attatch Callbacks for buttons
  button1.onPressed(onPress1);
  button2.onPressed(onPress2);
  button3.onPressed(onPress3);

  // Sets task LEDs to default red
  pixels.clear();
  for(int i = 0; i < numPixels; i++) {
    pixels.setPixelColor(i, pixels.Color(50,0,0));
    pixels.show();
  }
  // Connect to WiFi
  while (WiFi.status() != WL_CONNECTED) {
    delay(500);
    Serial.print (".");
  }

  timeClient.begin();
  
  // Print local IP adress
  Serial.println("");
  Serial.println("WiFi connected.");
  Serial.println("IP address: ");
  Serial.println(WiFi.localIP());

  // Begin server
  server.begin();
}

void loop() {
  // Listen for incoming clients
  WiFiClient client = server.available();

  u8g2.firstPage();
  do {
    // Draws Menu Boxes and check boxes
    for (int i = 0; i < 3; i++) {
      // Draws Tasks text
      u8g2.setFont(u8g2_font_t0_11_tf);
      u8g2.drawStr(3,17+(i*22),(tasks[i].text).data());
      
      u8g2.drawRFrame(0,i*22,103,20,3); //Draws Textboxes
      u8g2.drawRFrame(105,i*22,22,20,3); //Draws Checkboxes

      // Define cross draw coordinates
      int crossX = 109;
      int crossY = 16+(i*22);

      // Draw cross or tick based on task complete
      if (tasks[i].getComplete() == true) {
        u8g2.setFont(u8g2_font_unifont_t_symbols);
        u8g2.drawGlyph(crossX,crossY, 0x2715);
      } else if (tasks[i].getComplete() == false){
        u8g2.setFont(u8g2_font_unifont_t_symbols);
        u8g2.drawGlyph(crossX,crossY, 0x2714);
      }
      
    }
    
  } while ( u8g2.nextPage() );

  // Update LED conditions
  for (int i=0; i<3; i++) {
    // Turn off Led if task complete
    if (tasks[i].getComplete() == true) {
      pixels.setPixelColor(i, pixels.Color(50,0,0));
      pixels.show();
    } else {
      pixels.setPixelColor(i, pixels.Color(0,30,0));
      pixels.show();
    }
  }

  // Update time client
  timeClient.update();
  // Serial.println(timeClient.getHours());

  // Reset Tasks at 1 am
  if (timeClient.getHours() == 01) {
    for (int i = 0; i < 3; i++){
      tasks[i].resetTask();
    }
  }
  
  // Poll buttons
  button1.read();
  button2.read();
  button3.read();
}

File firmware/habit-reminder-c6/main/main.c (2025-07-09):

#include "oled_display.h"
#include "test_lvgl_ui.h"
#include "neopixel.h"
#include "freertos/FreeRTOS.h"
#include "freertos/task.h"
#include "freertos/queue.h"
#include "esp_log.h"
#include "driver/gpio.h"

/* Queue and state management */
QueueHandle_t task_queue;
bool task_states[3] = {false};

static const char *TAG = "main";

/* Button handling task */
void button_task(void *pvParam)
{
     const gpio_num_t button_pins[] = {GPIO_NUM_0, GPIO_NUM_1, GPIO_NUM_2};
     bool last_states[3] = {false};

     for (int i=0; i<3; i++) {
        gpio_reset_pin(button_pins[i]);
        gpio_set_direction(button_pins[i], GPIO_MODE_INPUT);
        gpio_set_pull_mode(button_pins[i], GPIO_PULLUP_ONLY);
     }

     while(1){
        for(int i = 0; i<3; i++) {
            bool current = !gpio_get_level(button_pins[i]); // Active low
            if (current && !last_states[i]) {
                task_states[i] = !task_states[i];
                xQueueSend(task_queue, &i, portMAX_DELAY);
            }
            last_states[i] = current;
        }
        vTaskDelay(pdMS_TO_TICKS(20));
     }
}

void app_main(void)
{
    /* Initialise hardware */
    oled_display_handle_t oled = oled_display_init();
    neopixel_handle_t leds = neopixel_init(3);

    /* Initial neopixel LEDs are red */
    neopixel_set_all(&leds, 50, 0, 0);
    neopixel_refresh(&leds);

    /* Create task queue */
    task_queue = xQueueCreate(5, sizeof(int));

    /* Initialise UI */
    lvgl_ui_demo(oled.lvgl_disp);

    /* Create tasks */
    xTaskCreate(button_task, "buttons", 2048, NULL, 2, NULL);

    /* Main loop */
    int task_index;
    while(1) {
        if(xQueueReceive(task_queue, &task_index, portMAX_DELAY)) {
            /* Update LED */
            neopixel_set_led(&leds, task_index,
                            task_states[task_index] ? 0 : 50, /* Red */
                            task_states[task_index] ? 10 : 0, /* Green */
                            0);

            /* Update checkbox */
            update_checkbox_state(task_index, task_states[task_index]);
            neopixel_refresh(&leds);

            ESP_LOGI(TAG, "Task %d %s", task_index+1,
                    task_states[task_index] ? "completed" : "pending");
        }
        lv_task_handler();
        vTaskDelay(pdMS_TO_TICKS(10));
    }
}

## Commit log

2023-10-27 Create habit_reminder.ino
    Initial arduino sketch upload. Updated crosses to be drawn with u8g2.drawGlyph instead of drawline
2023-10-27 Schematic with 3.3V LDO and OLED display
    [HabitReminder.kicad_pcb, HabitReminder.kicad_sch]
2023-10-28 Fully working basic firmware
    Menu with single button (short and long press) navigation. Using an array of objects for tasks, with appropriate functions for getting and changing attributes.
    [habit_reminder.ino]
2023-10-28 Add multi button support
2023-10-29 working with 3 single colour LEDs
    220 ohm resistors
2023-10-30 Started switch to Platform IO
2023-10-30 Change to previous version due to error
    Error in touch module
    [main.cpp]
2023-11-06 NeoPixel Implementation, Dev Board PCB V1
    [Dev_habit_reminder.kicad_pcb, Dev_habit_reminder.kicad_sch, Dev_habit_reminder_NoHeaders.kicad_pcb]
2023-11-06 PCB Track width definition, rerouting
    [Dev_habit_reminder.kicad_pcb, Dev_habit_reminder.kicad_sch]
2023-11-06 Added ground area and production files
    [Dev_habit_reminder-B_Cu.gbr, Dev_habit_reminder-B_Mask.gbr, Dev_habit_reminder-B_Paste.gbr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]
2023-11-08 Board re-routing
    [Dev_habit_reminder.kicad_pcb, Dev_habit_reminder.kicad_sch, Dev_habit_reminder_V1.kicad_pcb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]
2023-11-08 Changed button pins for efficient routing
    [Dev_habit_reminder.kicad_pcb, Dev_habit_reminder.kicad_sch]
2023-11-08 Start on V2 main-board and USB to UART
    [HabitReminderV2.kicad_pcb, HabitReminderV2.kicad_sch]
2023-11-19 Add prototype image
2023-11-19 schematic updates
    [HabitReminderV2.kicad_sch]
2024-03-26 E-paper initial design, connector
    [HabitReminderEPaper.kicad_pcb, HabitReminderEPaper.kicad_sch]
2024-04-03 Epaper initial prototype. Still needs main user buttons footprints
    [HabitReminderEPaper.kicad_sch]
2024-04-07 inital E-Paper prototype, OLED inital board finished
    [HabitReminderEPaper.kicad_pcb, HabitReminderEPaper.kicad_sch, HabitReminderOLED.kicad_pcb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]
2024-04-07 Create OLED Board Render
2024-04-07 Update OLED Board Render
2024-04-08 Move to SMD buttons, added LCSC designators
    [HabitReminderOLED.kicad_pcb, HabitReminderOLED.kicad_sch, bom.csv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]
2025-02-19 Updated OLED Board and created XAIO based board
    [HabitReminderOLED.kicad_pcb, HabitReminderOLED.kicad_sch, HabitReminderXAIO.kicad_pcb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]
2025-02-21 inital esp32 blink example
2025-02-21 working blinking on esp32-c6 xaio
2025-02-21 Flashing neo-pixel LEDs
2025-03-01 WIP: Moving functionality to seperate files for OLED screen and LED strip
2025-03-01 Moved OLED and NeoPixel LED functionality to own components
2025-03-02 Switched to RMT for LED strip control due to issues with SPI. Tested and working reliably on breadboard
    [main.c, neopixel.c]
2025-03-09 Flipped display and changed LED colour - working on new PCB
    [main.c, oled_display.c]
2025-03-10 Semi-working task display - LEDs responding correctly to button inputs
    [main.c, oled_display.c]
